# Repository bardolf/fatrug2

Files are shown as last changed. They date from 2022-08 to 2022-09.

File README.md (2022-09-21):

# FATRUG2

Fully automatic time project ([FAT](https://en.wikipedia.org/wiki/Fully_automatic_time)), based on [FireBeetle 2 ESP32-E IoT Microcontroller](https://www.dfrobot.com/product-2195.html). 

Usage demonstrated on [the videos](https://youtube.com/playlist?list=PLJGLIG7klYTQjR2PzYD64GDgjGLkynPeX).

Measures time between starting and finishing device. 
Basic features:
- ESP32-E IoT Microcontroller is a device brain.
- Ultrasonic distance sensor HC-SR04 with a threshold 60 - 80cm, could be more, didn't test.
- Reliable distance between devices up to 100m (depends on local conditions).
- Minimum measurement time is 100ms (avoiding false start).
- Systematic error 20-50ms, which I'm lazy to compansate.
- Able to run several hours on 2500mAh battery.
- Mountable to tripod via 1/4-20 UNC thread.

## Electronics

Schema and PCB drawn in KiCAD and files are part of the project. Original idea (and PCB) relied on laser sensor VL53L0X, however the measurement is too bad in noisy environment (sunny day). It was redesign to use ultrasonic sensor HC-SR04 instead. The ultrasonic sensor needs and TM1637 4-Digit LED need 5V (better results with 5V), step up to 5V was added. It is not yet reflected on PCB (maybe future updates), just connected with dupont wires.

Peripherials are following. 
- MCU
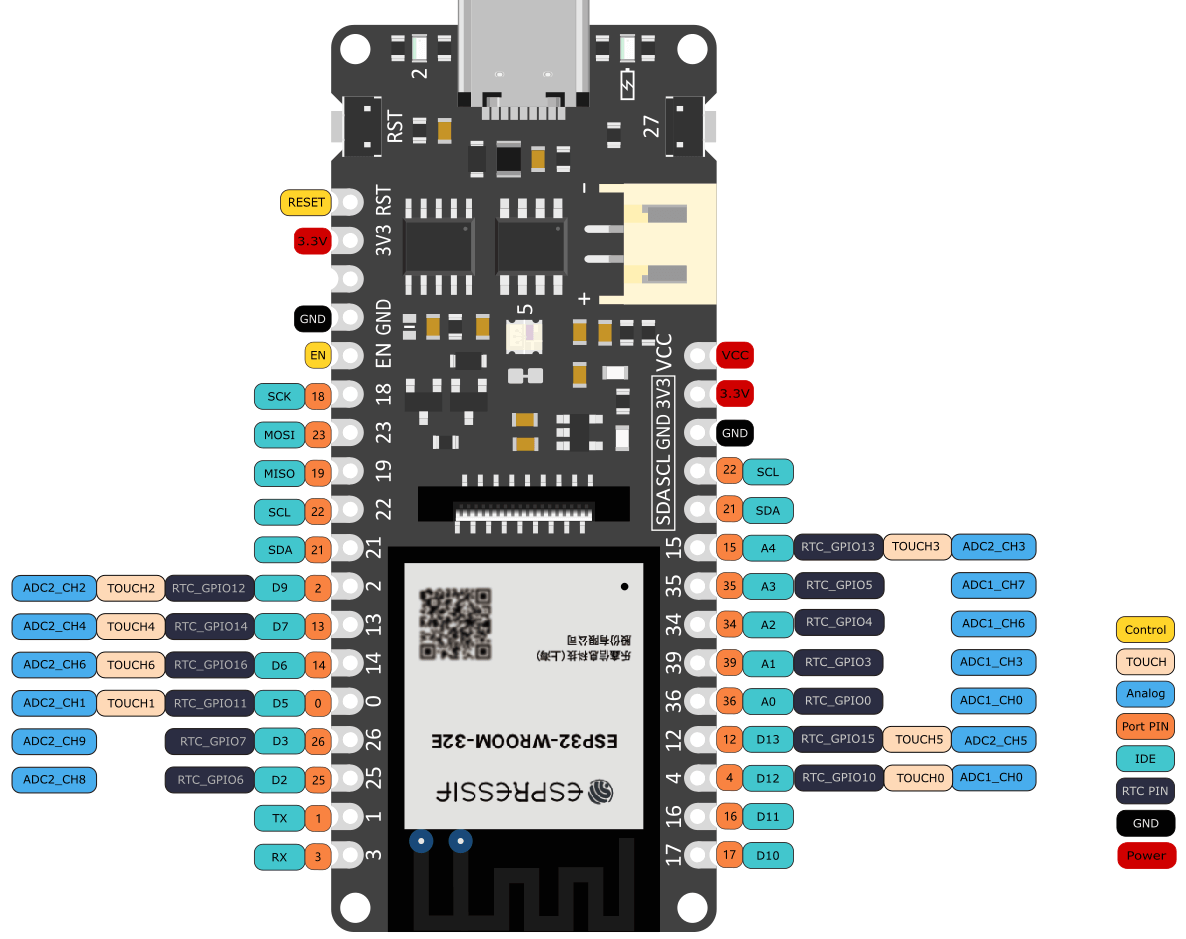
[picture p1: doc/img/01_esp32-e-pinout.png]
ESP32-E pinout


- ~~laser distance sensor - GY-VL53L0X I2, connected via connector labeled _laser_ (SDA, SCL, 3.3V, GND)~~

TODO: ultrasonic sensor

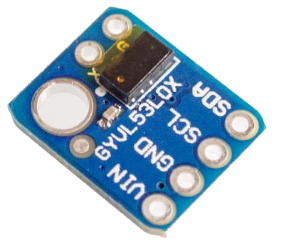
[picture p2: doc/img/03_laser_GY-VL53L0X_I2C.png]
GY-VL53L0X


- TM1637 4-Digit LED 0.56" 0.56inch 7 Segments Display, connected via connector labeled _7seg_. Beware: more common display is the one with colon wired and dots unwired. Choose based on your preferences.

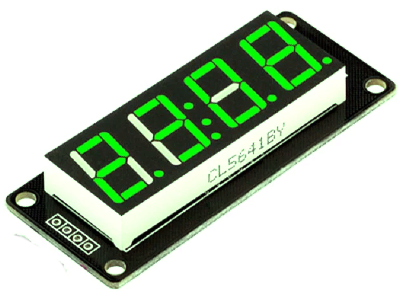
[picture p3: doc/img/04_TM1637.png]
TM1637


- RGB LED NeoPixel WS2812 8mm, connected via connector labeled _RGB LED_

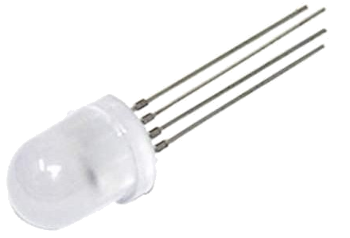
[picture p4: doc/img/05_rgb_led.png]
WS2812


- button (reset), connected to ground and PIN D2 (25) 

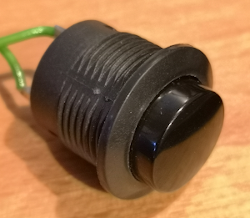
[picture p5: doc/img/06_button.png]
button


- LiPol Batterry 104050 2500mAh 3.7V JST-PH 2.0

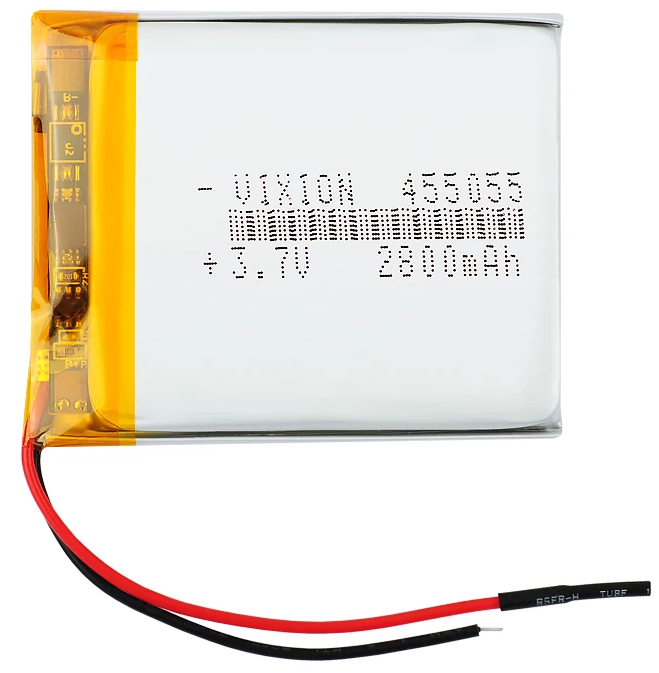
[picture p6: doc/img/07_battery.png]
battery


- switch ([aliexpress](https://www.aliexpress.com/item/1005003268288232.html?spm=a2g0o.order_detail.0.0.5ad3f19ccqQfnJ))

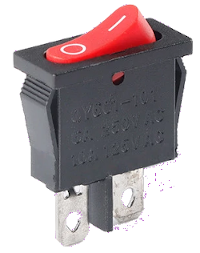
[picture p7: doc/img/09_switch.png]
switch


- 2x resistor 20k - for battery capacity measurement on PIN A0 (36)

- some JST-PH connectors, DUPONT connectors

If you make your own BOM don't forget to [multiply it by two](https://youtube.com/clip/UgkxrPXdP5GEu_9O2kQU0yOqQVvTavGrz9Ro) - you need 2 boxes.

TODO: antennas

### PCB

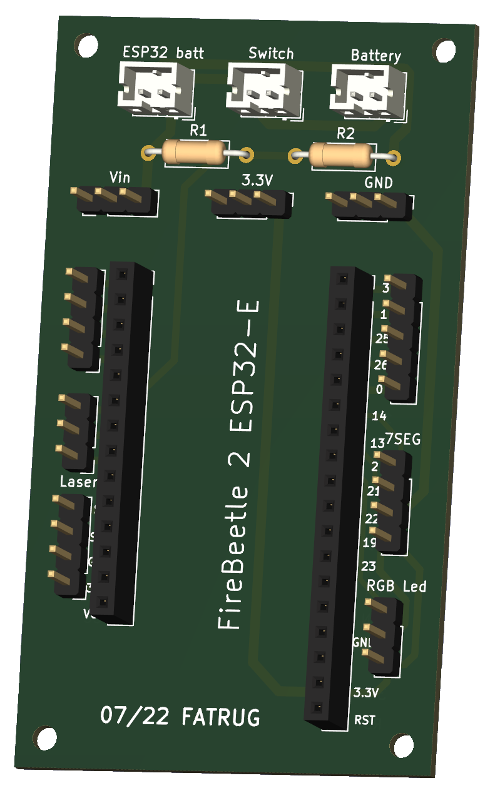
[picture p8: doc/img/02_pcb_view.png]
PCB


## Box

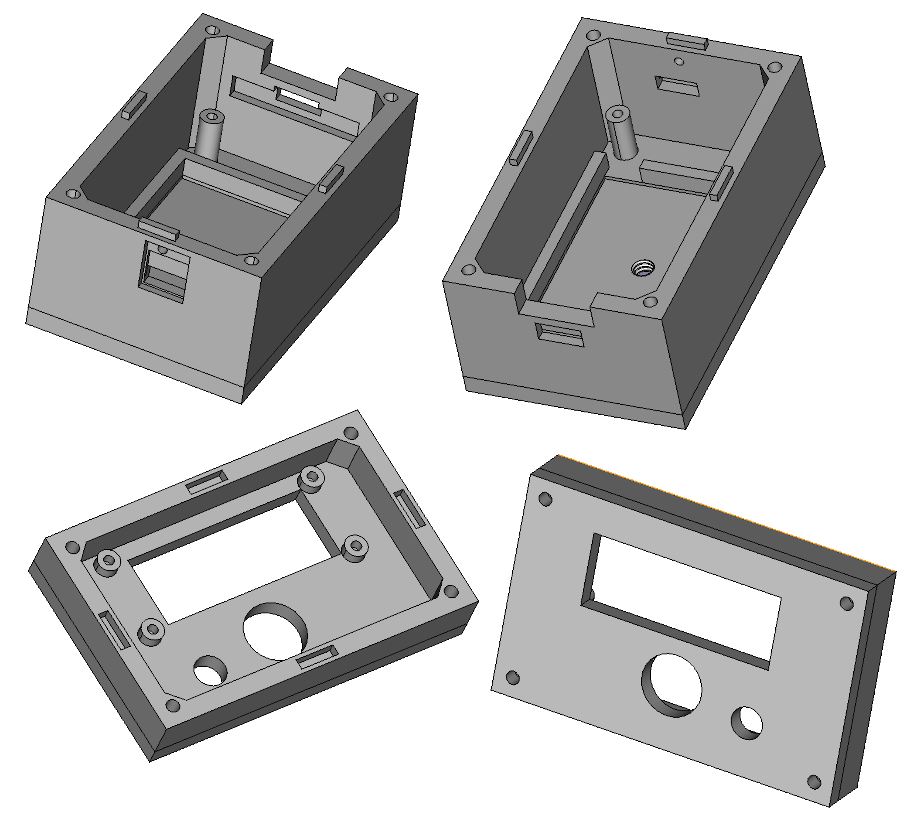
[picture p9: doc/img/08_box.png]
Box


## State Diagram 

## Photos

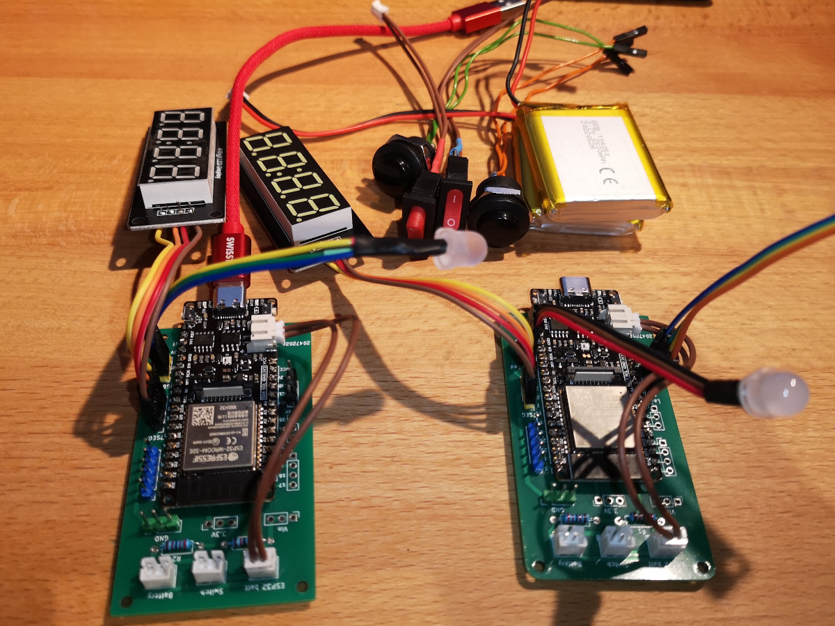
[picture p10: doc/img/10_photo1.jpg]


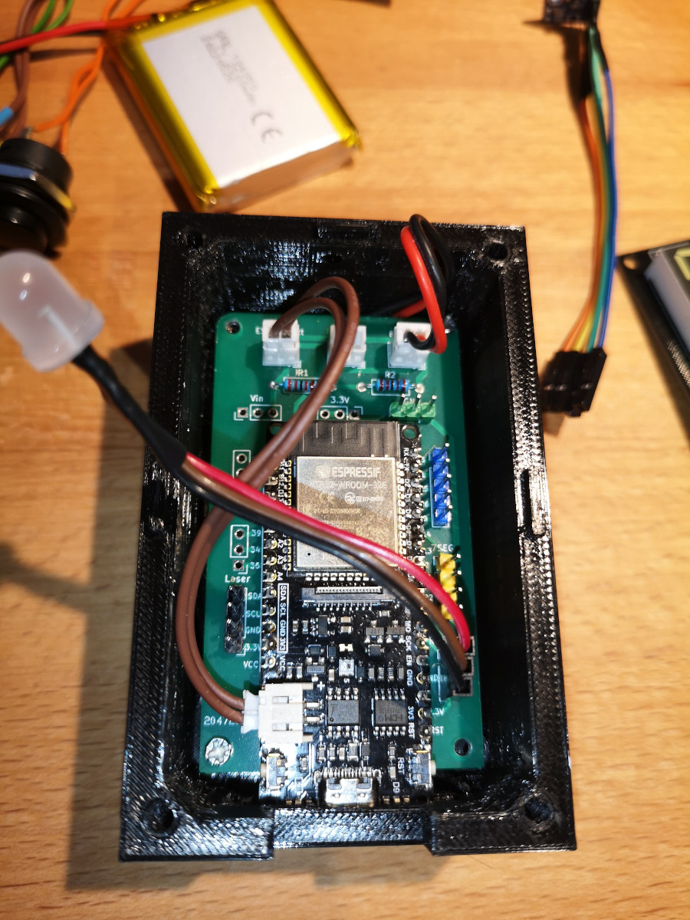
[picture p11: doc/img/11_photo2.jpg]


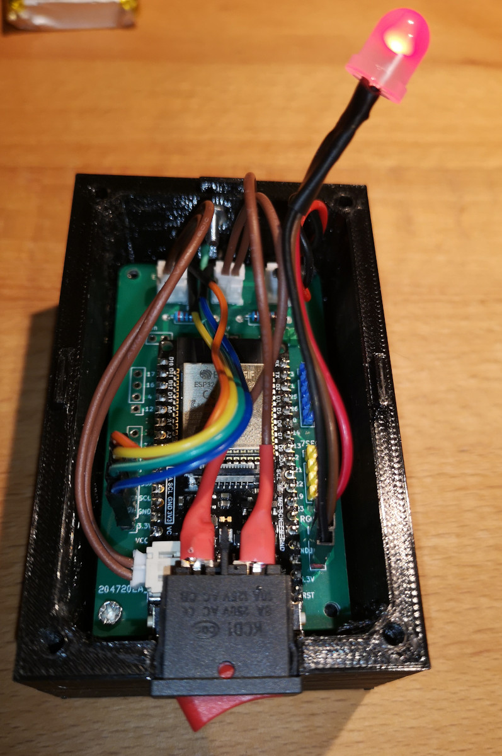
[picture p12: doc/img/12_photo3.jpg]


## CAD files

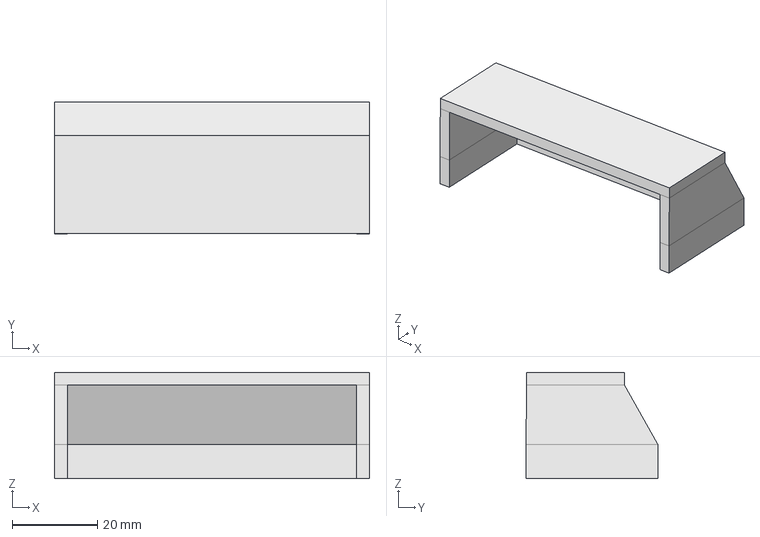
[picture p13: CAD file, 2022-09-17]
freecad/v2/fatrug2.FCStd
74.0 x 31.0 x 25.0 mm

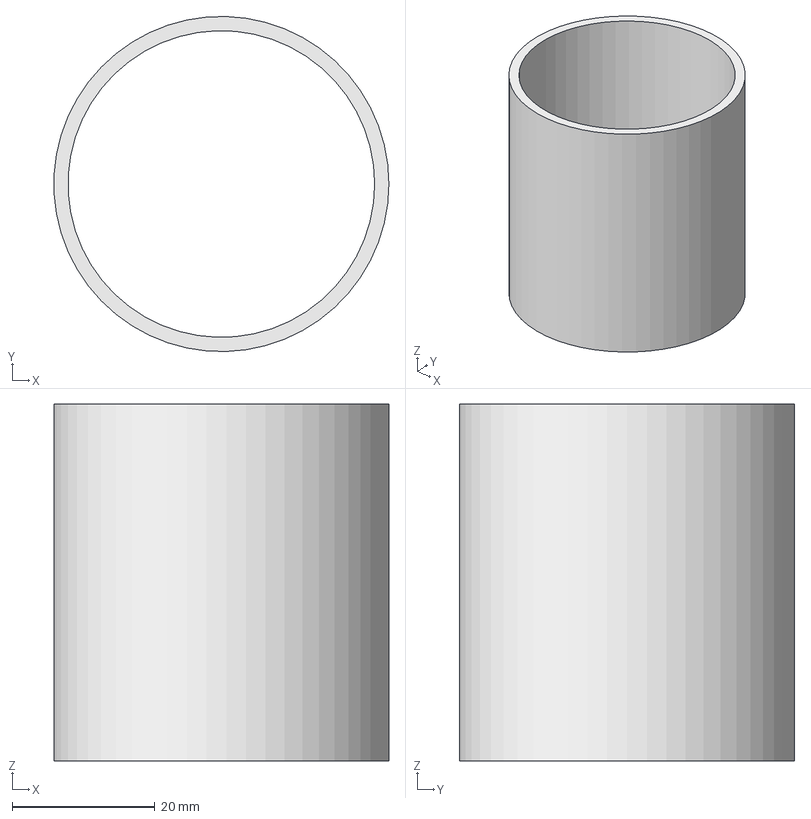
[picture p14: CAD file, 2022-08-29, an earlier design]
freecad/v1/fatrug2.FCStd
47.0 x 47.0 x 50.0 mm

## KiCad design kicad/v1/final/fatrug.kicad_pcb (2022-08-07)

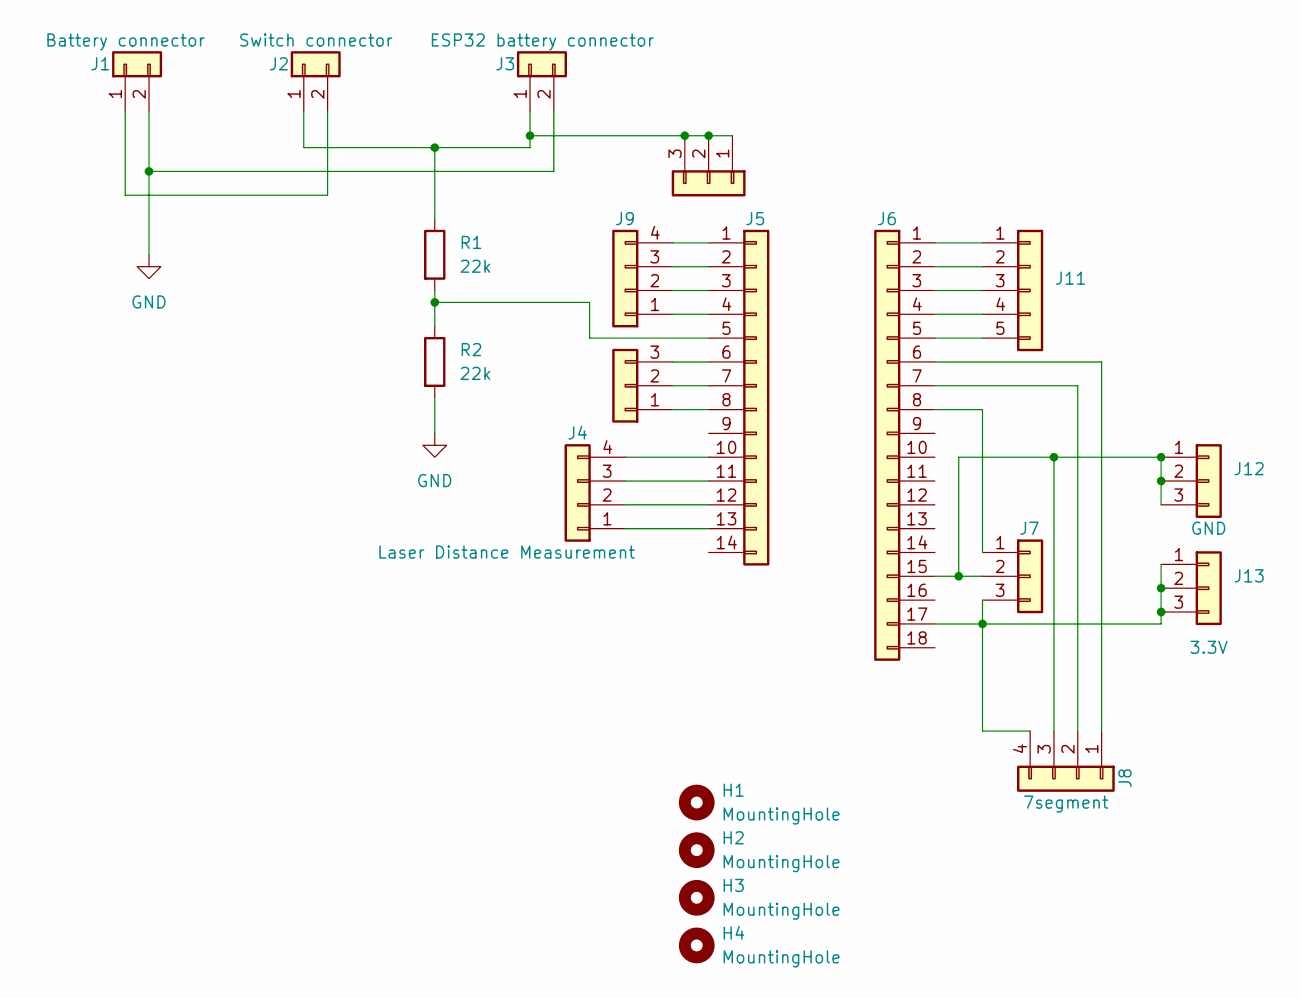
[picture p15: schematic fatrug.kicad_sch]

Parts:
H1, H2, H3, H4: MountingHole; MountingHole_2.5mm
J1, J2, J3: Conn_01x02; JST_PH_B2B-PH-K_1x02_P2.00mm_Vertical
J4, J8, J9: Conn_01x04; PinHeader_1x04_P2.54mm_Vertical
J5: Conn_01x14; PinSocket_1x14_P2.54mm_Vertical
J6: Conn_01x18; PinSocket_1x18_P2.54mm_Vertical
J7, J10, J12, J13: Conn_01x03; PinHeader_1x03_P2.54mm_Vertical
J11: Conn_01x05; PinHeader_1x05_P2.54mm_Vertical
R1, R2: 22k; R_Axial_DIN0207_L6.3mm_D2.5mm_P10.16mm_Horizontal

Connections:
GND: J1.2, J3.2, R2.2
unnamed: J1.1, J2.2
unnamed: J4.1, J5.13
unnamed: J4.2, J5.12
unnamed: J4.3, J5.11
unnamed: J4.4, J5.10
unnamed: J5.1, J9.4
unnamed: J5.2, J9.3
unnamed: J5.3, J9.2
unnamed: J5.4, J9.1
unnamed: J5.5, R1.2, R2.1
unnamed 11: J5.6; also elsewhere on the board
unnamed 12: J5.7; also elsewhere on the board
unnamed 13: J5.8; also elsewhere on the board
unnamed: J6.6, J8.1
unnamed: J6.7, J8.2
unnamed: J6.8, J7.1
unnamed: J6.17, J7.3, J8.4, J13.1, J13.2, J13.3
unnamed: J2.1, J3.1, J10.1, J10.2, J10.3, R1.1
unnamed: J6.1, J11.1
unnamed: J6.2, J11.2
unnamed: J6.3, J11.3
unnamed: J6.4, J11.4
unnamed: J6.5, J11.5
unnamed: J6.15, J7.2, J8.3, J12.1, J12.2, J12.3

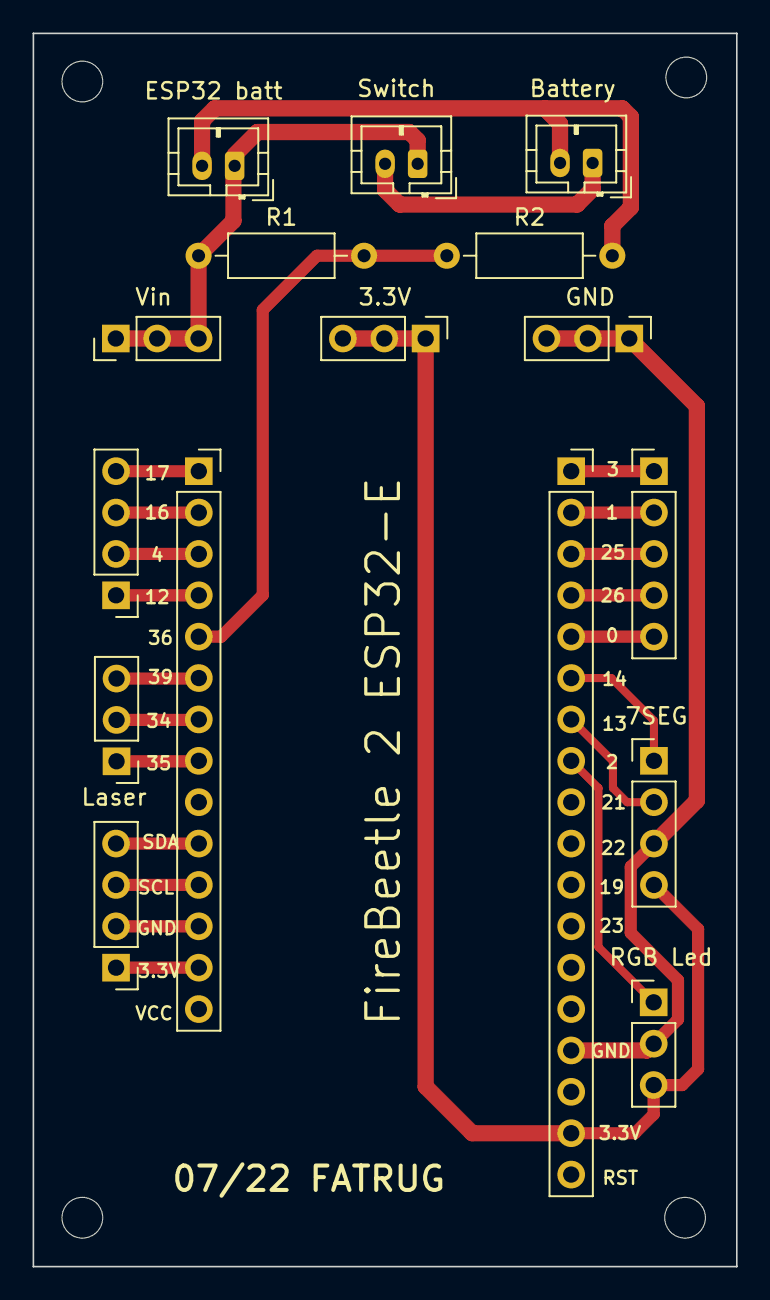
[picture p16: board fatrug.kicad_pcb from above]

Board: 2 copper layers, 43.2 x 75.7 mm, 20 parts (0 on the bottom side), 25 nets.

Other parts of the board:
J14: Conn_01x03; PinHeader_1x03_P2.54mm_Vertical

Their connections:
unnamed 11: J14.3; also elsewhere on the board
unnamed 12: J14.2; also elsewhere on the board
unnamed 13: J14.1; also elsewhere on the board

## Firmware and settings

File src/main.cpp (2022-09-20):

#include <Arduino.h>
#include <Bounce2.h>
#include <FastLED.h>
#include <TM1637Display.h>
#include <WiFi.h>
#include <Wire.h>
#include <esp_now.h>
#include <esp_wifi.h>

#include "battery.h"
#include "detector.h"
#include "display.h"
#include "logging.h"
#include "rgbled.h"

// Constants
#define DEVICE_TYPE 0  // defines whether is it start (0) or finish (1) device 

#define RESET_BUTTON_PIN 0  // ext. reset button pin

typedef enum {
    STATE_UNKNOWN,
    STATE_START,
    STATE_READY,
    STATE_RUN_CHECK,
    STATE_RUN,
    STATE_FINISH,
    STATE_SEND_ERRROR
} State;

// used for logging/debuggin purposes
const char *stateName(State state) {
    static char const *stateNames[7] = {"STATE_UNKNOWN", "STATE_START", "STATE_READY", "STATE_RUN_CHECK", "STATE_RUN", "STATE_FINISH", "STATE_SEND_ERRROR"};
    if (state >= 0 && state < 7) {
        return stateNames[state];
    } else {
        return "UNDEFINED";
    }
}

typedef enum {
    EVENT_SEND_ERROR,
    EVENT_BUTTON_RESET,
    EVENT_MESSAGE_INIT,
    EVENT_MESSAGE_ACK,
    EVENT_MESSAGE_FINISH,
    EVENT_DETECTOR_OBJECT_LEFT,
    EVENT_DETECTOR_OBJECT_ARRIVED,
    EVENT_RUN_CONFIRMED,
    EVENT_TIMEOUT
} Event;

// used for logging/debuggin purposes
const char *eventName(Event event) {
    static char const *eventNames[9] = {"EVENT_SEND_ERROR", "EVENT_BUTTON_RESET", "EVENT_MESSAGE_INIT", "EVENT_MESSAGE_ACK", "EVENT_MESSAGE_FINISH",
                                        "EVENT_DETECTOR_OBJECT_LEFT", "EVENT_DETECTOR_OBJECT_ARRIVED", "EVENT_RUN_CONFIRMED", "EVENT_TIMEOUT"};
    if (event >= 0 && event < 9) {
        return eventNames[event];
    } else {
        return "UNDEFINED";
    }
}

// Types
typedef struct Message {
    Event event;
    unsigned long time;
} Message;

// Global Variables
State currentState = STATE_UNKNOWN;
uint32_t stateChangeTime = 0;
RgbLed rgbLed;
Bounce bounce;
Display display;
Battery battery;
Detector detector;
uint32_t startTime = 0;
uint32_t measuredTime = 0;

QueueHandle_t sendQueue;
QueueHandle_t stateMachineEventQueue;

uint8_t startDeviceAddress[] = {0x08, 0x3A, 0xF2, 0x3A, 0x81, 0xFC};   // white
uint8_t finishDeviceAddress[] = {0x08, 0x3A, 0xF2, 0x3A, 0x81, 0x60};  // red
// uint8_t finishDeviceAddress[] = {0x08, 0x3A, 0xF2, 0x3A, 0x5D, 0xA0}; //breadboard
esp_now_peer_info_t peerInfo;

/**
 * Specifies whether is the start (master) device or not.
 * Usually based on harware configuration.
 */
boolean isStartDevice() {
    return DEVICE_TYPE == 0;
}

void addSendQueue(Message message) {
    if (xQueueSend(sendQueue, &message, 0) != pdTRUE) {
        Log.errorln("Problem while putting a message to a send queue, is it full?");
    }
}

void addStateMachineQueue(Message message) {
    if (xQueueSend(stateMachineEventQueue, &message, 0) != pdTRUE) {
        Log.errorln("Problem while putting a message to a state machine queue, is it full?");
    }
}

// Callback when data is sent
void OnDataSent(const uint8_t *mac_addr, esp_now_send_status_t status) {
    if (status == ESP_NOW_SEND_FAIL) {
        if (currentState != STATE_START) {
            Message message;
            message.event = EVENT_SEND_ERROR;
            addStateMachineQueue(message);
        }
    }
}

void OnDataRecv(const uint8_t *mac, const uint8_t *incomingData, int len) {
    Message message;
    memcpy(&message, incomingData, sizeof(message));
    Log.infoln("Received message event %s (%d)", eventName(message.event), message.time);
    addStateMachineQueue(message);
}

void readResetButtonTask(void *pvParameters) {
    while (1) {
        vTaskDelay(50 / portTICK_PERIOD_MS);
        bounce.update();
        if (bounce.changed()) {
            int deboucedInput = bounce.read();
            if (deboucedInput == HIGH) {
                Message message;
                message.event = EVENT_BUTTON_RESET;
                addStateMachineQueue(message);
                addSendQueue(message);
            }
        }
    }
}

void updateRgbLedTask(void *pvParameters) {
    while (1) {
        rgbLed.update();
        vTaskDelay(50 / portTICK_PERIOD_MS);
    }
}

void updateBatteryTask(void *pvParameters) {
    while (1) {
        battery.update();
        int prct = battery.getPercentage();
        for (int i = 0; i < 4; i++) {
            vTaskDelay(1000 / portTICK_PERIOD_MS);
            battery.update();
            prct = max(prct, battery.getPercentage());
        }

        Log.infoln("Battery value %d prct", prct);
        if (prct < 10) {
            Log.infoln("Battery REDb");
            rgbLed.setBlinkingColor(CRGB::Red, 20);
        } else if (prct < 20) {
            Log.infoln("Battery RED");
            rgbLed.setSolidColor(CRGB::Red, 20);
        } else if (prct < 40) {
            Log.infoln("Battery YELLOW");
            rgbLed.setSolidColor(CRGB::Yellow, 20);
        } else if (prct < 60) {
            Log.infoln("Battery GreenYellow");
            rgbLed.setSolidColor(CRGB::GreenYellow, 20);
        } else {
            Log.infoln("Battery GREEN");
            rgbLed.setSolidColor(CRGB::Green, 20);
        }
        vTaskDelay(1000 * 60 / portTICK_PERIOD_MS);
    }
}

void updateDisplay(void *pvParameters) {
    while (1) {
        display.update();
        vTaskDelay(10 / portTICK_PERIOD_MS);
    }
}

void stateMachineStartDeviceTask(void *pvParameters) {
    Message message;
    while (1) {
        if (xQueueReceive(stateMachineEventQueue, (void *)&message, 10000) == pdTRUE) {
            Log.infoln("SM: state %s, event %s", stateName(currentState), eventName(message.event));
            if (message.event == EVENT_BUTTON_RESET) {
                currentState = STATE_START;
                display.showConnecting();
                detector.stopMeasurement();
                continue;
            }
            if (message.event == EVENT_SEND_ERROR) {
                display.showError();
                detector.stopMeasurement();
                continue;
            }
            switch (currentState) {
                case STATE_START:
                    detector.stopMeasurement();
                    if (message.event == EVENT_MESSAGE_ACK) {
                        detector.startMeasurement();
                        display.showZeroTime();
                        currentState = STATE_READY;
                        stateChangeTime = millis();
                    }
                    break;
                case STATE_READY:
                    if (message.event == EVENT_DETECTOR_OBJECT_LEFT) {
                        currentState = STATE_RUN_CHECK;
                        stateChangeTime = millis();
                        startTime = millis() - message.time;        //we have started message.time ago
                        display.showTimeContinuously(message.time); //show correct time starting with message.time
                    }
                    break;
                case STATE_RUN_CHECK:
                    if (message.event == EVENT_DETECTOR_OBJECT_ARRIVED) {
                        currentState = STATE_READY;
                    } else if (message.event == EVENT_RUN_CONFIRMED) {
                        currentState = STATE_RUN;
                        stateChangeTime = millis();
                        detector.stopMeasurement();
                        message.time = millis() - startTime;
                        addSendQueue(message);                        
                    }
                    break;
                case STATE_RUN:
                    if (message.event == EVENT_DETECTOR_OBJECT_ARRIVED) {
                        measuredTime = millis() - startTime - message.time; //current time - start time - detector compensation time
                        display.showTime(measuredTime);
                        message.event = EVENT_MESSAGE_FINISH;
                        message.time = measuredTime;
                        currentState = STATE_FINISH;
                        stateChangeTime = millis();
                        addSendQueue(message);
                    }
                    break;
                case STATE_FINISH:
                    if (message.event == EVENT_TIMEOUT) {
                        currentState = STATE_START;
                        stateChangeTime = millis();
                    }
                    break;
                default:
                    break;
            }
            Log.infoln("SM: new state %s", stateName(currentState));
        }
    }
}

void stateMachineFinishDeviceTask(void *pvParameters) {
    Message message;
    while (1) {
        if (xQueueReceive(stateMachineEventQueue, (void *)&message, 10000) == pdTRUE) {
            Log.infoln("SM: state %s, event %s", stateName(currentState), eventName(message.event));
            if (message.event == EVENT_BUTTON_RESET) {
                currentState = STATE_START;
                detector.stopMeasurement();
                display.showConnecting();
                continue;
            }
            switch (currentState) {
                case STATE_START:
                    detector.stopMeasurement();
                    if (message.event == EVENT_MESSAGE_INIT) {
                        Message message;
                        message.event = EVENT_MESSAGE_ACK;
                        addSendQueue(message);
                        display.showZeroTime();
                        currentState = STATE_READY;
                        stateChangeTime = millis();
                    }
                    break;
                case STATE_READY:
                    display.showZeroTime();
                    if (message.event == EVENT_RUN_CONFIRMED) {
                        display.showTimeContinuously(message.time);
                        detector.startMeasurement();
                        currentState = STATE_RUN;
                        stateChangeTime = millis();
                        startTime = message.time;
                    }
                    break;
                case STATE_RUN:
                    if (message.event == EVENT_DETECTOR_OBJECT_ARRIVED) {
                        detector.stopMeasurement();                       
                    } else if (message.event == EVENT_MESSAGE_FINISH) {
                        measuredTime = message.time;
                        display.showTime(measuredTime);
                        currentState = STATE_FINISH;
                        stateChangeTime = millis();
                    }
                    break;
                case STATE_FINISH:
                    if (message.event == EVENT_TIMEOUT) {
                        currentState = STATE_START;
                        stateChangeTime = millis();
                    }
                    break;
                default:
                    break;
            }
            Log.infoln("SM: new state %s", stateName(currentState));
        }
    }
}

void stateMachineTask(void *pvParameters) {
    if (isStartDevice()) {
        stateMachineStartDeviceTask(pvParameters);
    } else {
        stateMachineFinishDeviceTask(pvParameters);
    }
}

void readDetectorTask(void *pvParameters) {
    while (1) {
        DetectedObjectState detectedObjectState = detector.read();
        if (detectedObjectState == ARRIVED) {
            Message message;
            message.event = EVENT_DETECTOR_OBJECT_ARRIVED;
            message.time = detector.getCompensationTime();
            Log.info("Compensation time (arrived) %d", detector.getCompensationTime());
            addSendQueue(message);
            addStateMachineQueue(message);
            Log.infoln("Object arrived");
        } else if (detectedObjectState == LEFT) {
            Message message;
            message.event = EVENT_DETECTOR_OBJECT_LEFT;
            message.time = detector.getCompensationTime();            
            Log.info("Compensation time (arrived) %d", detector.getCompensationTime());
            addStateMachineQueue(message);
            Log.infoln("Object left");
        }
        vTaskDelay(5 / portTICK_PERIOD_MS);
    }
}

void establishCommunicationTask(void *pvParameters) {
    while (1) {
        if (isStartDevice() && currentState == STATE_START) {
            Message message;
            message.event = EVENT_MESSAGE_INIT;
            Log.infoln("Establishing communication...");
            addSendQueue(message);
        }
        vTaskDelay(300 / portTICK_PERIOD_MS);
    }
}

void communicationTask(void *pvParameters) {
    Message message;
    while (1) {
        if (xQueueReceive(sendQueue, (void *)&message, 10000) == pdTRUE) {
            Log.infoln("Sending message %s (%d) from %s", eventName(message.event), message.time, WiFi.macAddress().c_str());
            uint8_t *address = startDeviceAddress;
            esp_err_t result = esp_now_send(peerInfo.peer_addr, (uint8_t *)&message, sizeof(message));
            if (result != ESP_OK) {
                Log.errorln("Error sending the data");
            }
        }
    }
}

void additionalDelayedTask(void *pvParameters) {
    while (1) {
        if (isStartDevice() && currentState == STATE_RUN_CHECK && ((millis() - startTime) >= 100)) {
            Message message;
            message.event = EVENT_RUN_CONFIRMED;
            addStateMachineQueue(message);
        } else if (currentState == STATE_FINISH && ((millis() - stateChangeTime) > 8000)) {
            Message message;
            message.event = EVENT_TIMEOUT;
            addStateMachineQueue(message);
        }
        vTaskDelay(50 / portTICK_PERIOD_MS);
    }
}

void setup() {
    Serial.begin(115200);

    // initialize logging
    while (!Serial && !Serial.available()) {
    }
    Log.begin(LOG_LEVEL_ERROR, &Serial);
    Log.setPrefix(printPrefix);
    Log.setShowLevel(false);
    Log.infoln("START");

    // initialize queues
    stateMachineEventQueue = xQueueCreate(10, sizeof(Message));
    sendQueue = xQueueCreate(10, sizeof(Message));

    // reset button initialization
    bounce.attach(RESET_BUTTON_PIN, INPUT_PULLUP);
    bounce.interval(10);

    // rgb and display initialization
    rgbLed.init();
    display.init();

    // detector initialization
    detector.init();

    // communication initialization
    WiFi.mode(WIFI_MODE_STA);
    esp_wifi_set_protocol(WIFI_IF_STA, WIFI_PROTOCOL_LR);
    if (esp_now_init() != ESP_OK) {
        Log.errorln("Error initializing ESP-NOW");
        return;
    }
    Log.infoln("MAC Address: %s", WiFi.macAddress().c_str());

    if (isStartDevice()) {
        memcpy(peerInfo.peer_addr, finishDeviceAddress, 6);
    } else {
        memcpy(peerInfo.peer_addr, startDeviceAddress, 6);
    }
    peerInfo.channel = 0;
    peerInfo.encrypt = false;
    if (esp_now_add_peer(&peerInfo) != ESP_OK) {
        Log.errorln("Failed to add peer");
        return;
    }
    esp_now_register_send_cb(OnDataSent);
    esp_now_register_recv_cb(OnDataRecv);

    xTaskCreatePinnedToCore(updateRgbLedTask, "Upd. RGB", 8000, NULL, 2, NULL, ARDUINO_RUNNING_CORE);
    xTaskCreatePinnedToCore(updateBatteryTask, "Upd. battery", 8000, NULL, 2, NULL, ARDUINO_RUNNING_CORE);
    xTaskCreatePinnedToCore(updateDisplay, "Upd. display", 8000, NULL, 2, NULL, ARDUINO_RUNNING_CORE);
    xTaskCreatePinnedToCore(stateMachineTask, "State machine", 8000, NULL, 2, NULL, ARDUINO_RUNNING_CORE);
    xTaskCreatePinnedToCore(readDetectorTask, "Read detector", 8000, NULL, 6, NULL, ARDUINO_RUNNING_CORE);
    xTaskCreatePinnedToCore(readResetButtonTask, "Reset button", 8000, NULL, 2, NULL, ARDUINO_RUNNING_CORE);
    xTaskCreatePinnedToCore(communicationTask, "Communication", 8000, NULL, 4, NULL, 0);
    if (isStartDevice()) {
        xTaskCreatePinnedToCore(establishCommunicationTask, "Estab. communication", 8000, NULL, 1, NULL, ARDUINO_RUNNING_CORE);
    }
    xTaskCreatePinnedToCore(additionalDelayedTask, "Add. delayed", 8000, NULL, 3, NULL, ARDUINO_RUNNING_CORE);

    // when started let's reset the peer
    Message message;
    message.event = EVENT_BUTTON_RESET;
    addSendQueue(message);

    // start the SM
    currentState = STATE_START;
    display.showConnecting();
}

void loop() {
    vTaskDelay(10000 / portTICK_PERIOD_MS);  // do nothing in loop
}

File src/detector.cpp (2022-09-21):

#include "detector.h"

#include "logging.h"

Detector::Detector() {
    _detectorPulseInTimeout = 2 * (unsigned long)((float)RANGE_THRESHOLD_CM / (float)SOUND_SPEED_HALF);
}

void Detector::startMeasurement() {
    _prevObjectDetected = false;
    _measurementEnabled = true;
    _prevPrevDistance = _prevDistance = _distance = 0;
}

void Detector::stopMeasurement() {
    _measurementEnabled = false;
}

void Detector::init() {
    pinMode(TRIGGER_PIN, OUTPUT);
    pinMode(ECHO_PIN, INPUT_PULLDOWN);
}

uint32_t Detector::getCompensationTime() {
    return _time - _prevPrevTime;
}

float Detector::measureDistance() {
    digitalWrite(TRIGGER_PIN, LOW);
    delayMicroseconds(5);
    digitalWrite(TRIGGER_PIN, HIGH);
    delayMicroseconds(1);
    digitalWrite(TRIGGER_PIN, LOW);
    // Serial.print(millis());
    // Serial.print("ms ");
    long duration = pulseIn(ECHO_PIN, HIGH, _detectorPulseInTimeout);
    // Serial.print(millis());
    // Serial.print("ms ~ ");
    // Serial.println(duration);
    if (duration == 0) {  // pulseIn timeout
        return 10 * RANGE_THRESHOLD_CM;
    }
    return duration * SOUND_SPEED_HALF;
}

DetectedObjectState Detector::read() {
    if (_measurementEnabled) {
        _prevPrevDistance = _prevDistance;
        _prevDistance = _distance;
        _distance = measureDistance();

        _prevPrevTime = _prevTime;
        _prevTime = _time;
        _time = millis();

        if (_distance > 0 && _prevDistance > 0 && _prevPrevDistance > 0 &&
            _distance > RANGE_THRESHOLD_CM && _prevDistance > RANGE_THRESHOLD_CM && _prevPrevDistance > RANGE_THRESHOLD_CM && _prevObjectDetected) {
            _prevObjectDetected = false;
            Log.infoln("LEFT %F cm (%Fcm, %Fcm)", _distance, _prevDistance, _prevPrevDistance);
            return LEFT;
        } else if (_distance > 0 && _prevDistance > 0 && _prevPrevDistance > 0 &&
                   _distance <= RANGE_THRESHOLD_CM && _prevDistance <= RANGE_THRESHOLD_CM && _prevPrevDistance <= RANGE_THRESHOLD_CM &&
                   abs(1 - _distance / _prevDistance) < DISTANCE_RELATIVE_TOLERANCE && abs(1 - _prevPrevDistance / _prevPrevDistance) < DISTANCE_RELATIVE_TOLERANCE && !_prevObjectDetected) {
            _prevObjectDetected = true;
            Log.infoln("ARRIVED %F cm (%Fcm, %Fcm)", _distance, _prevDistance, _prevPrevDistance);
            return ARRIVED;
        }
    }
    return NONE;
}

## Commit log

2022-08-07 kicad files
    [fatrug-B_Cu.gbr, fatrug-B_Mask.gbr, fatrug-B_Paste.gbr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]
2022-08-14 freecad box added
    [fatrug2.FCStd]
2022-08-14 freecad box
    [fatrug2.FCStd]
2022-08-20 doc updated
    [fatrug2.FCStd]
2022-08-21 battery introduced
2022-08-23 comment on battery capacity
2022-08-26 state machine, detector
    [partitions_singleapp_large.csv]
2022-08-29 box updated
    [fatrug2.FCStd]
2022-09-04 boxes for ultrasonic sensors
    [fatrug2.FCStd]
2022-09-05 boxe size increased
    [fatrug2.FCStd]
2022-09-08 battery percentage
